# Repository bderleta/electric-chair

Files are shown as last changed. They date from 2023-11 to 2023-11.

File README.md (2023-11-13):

# Electric Chair

AVR Parallel Programmer

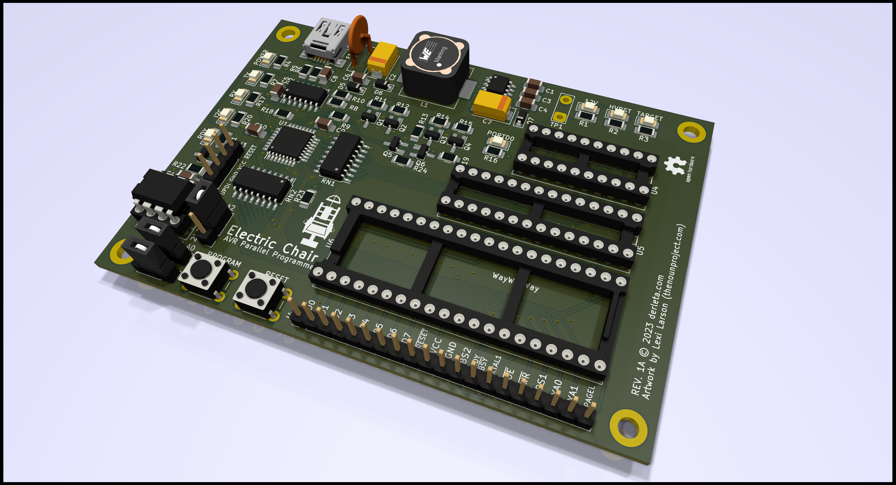
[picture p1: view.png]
Board View REV. 1


## Overview

This is an application of AVRxDB32 MCU with MCP2221A USB-UART/USB-I2C interface chip, implementing parallel programming protocol for ATmega32 and 
other MCUs with similar programming interface. 12V programming voltage is generated onboard by MAX632-based converter.

Firmware stub for AVR128DB32 is available at https://github.com/bderleta/electric-chair-firmware, probably it can be built for other chips from
AVRxDB32 family. The MCP2221A is running at its stock settings and no reconfiguration is necessary, though adjustment of power requirement limit is 
recommended.

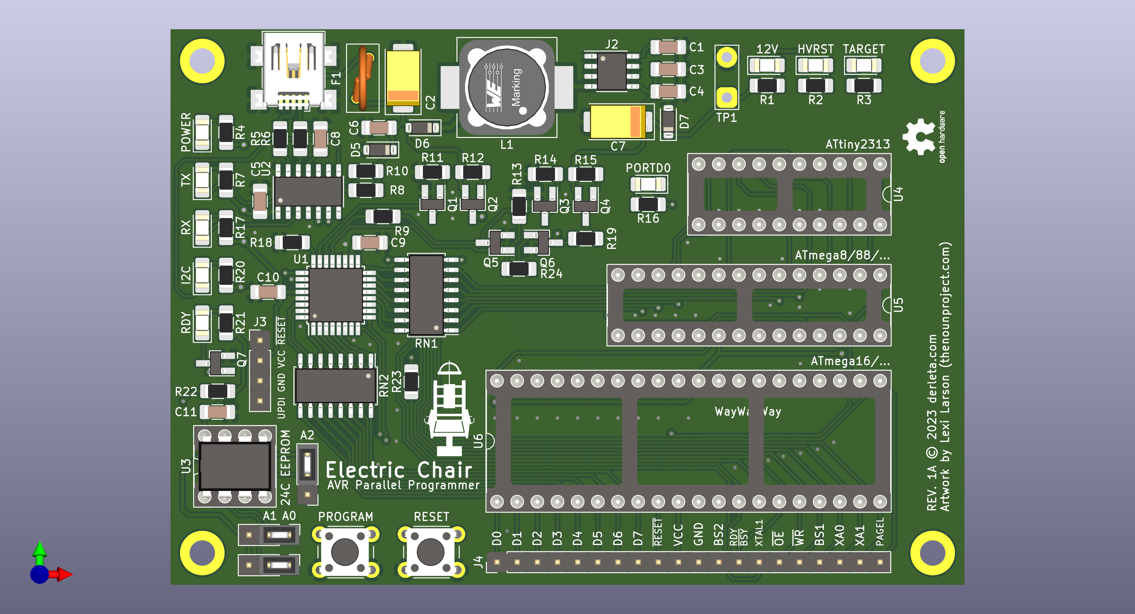
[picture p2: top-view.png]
Board View REV. 1


## Known flaws of first revision
- Significant USB inrush current (can be adjusted by lowering C2 value, but...)
- Converter input ripple of about 100mV (still testing)
- "12V" and "HVRST" leds are consuming majority of converter's output :)

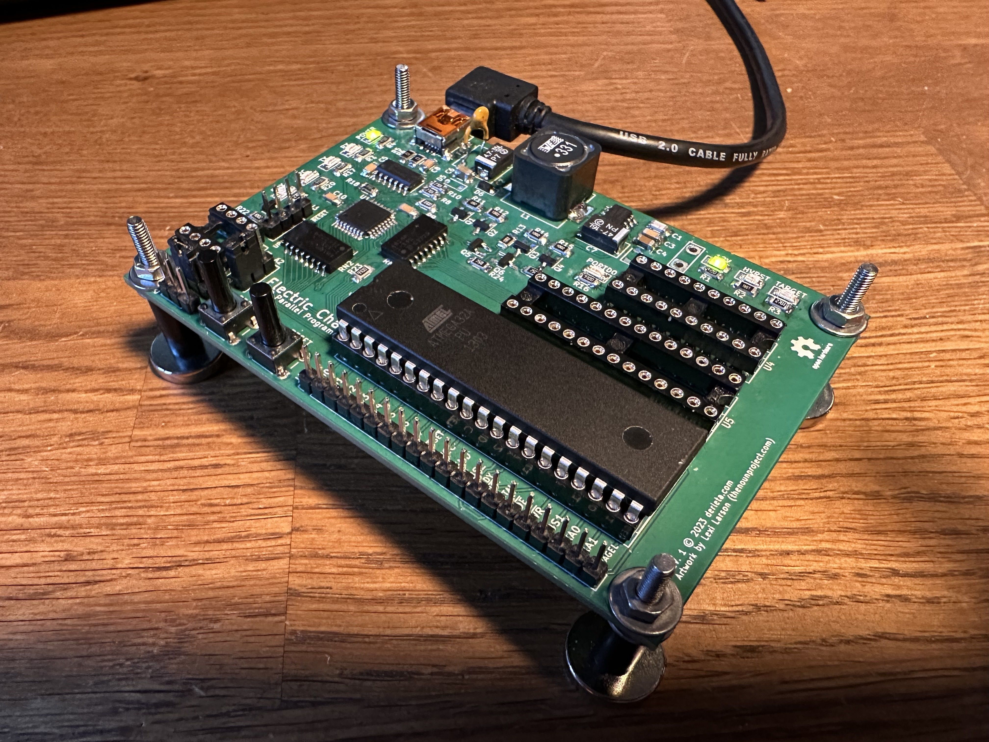
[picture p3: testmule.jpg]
Board View REV. 1 test mule


## Changes coming in second revision

- MAX662-based converter
- XTAL1 line connected to dedicated waveform output of AVR
- PROGRAM button connected to the CCL input in order to enable debouncing using CCL filters
- Elimination of 20-pin socket, instead DIP-40 and DIP-28 ZIF sockets will be placed

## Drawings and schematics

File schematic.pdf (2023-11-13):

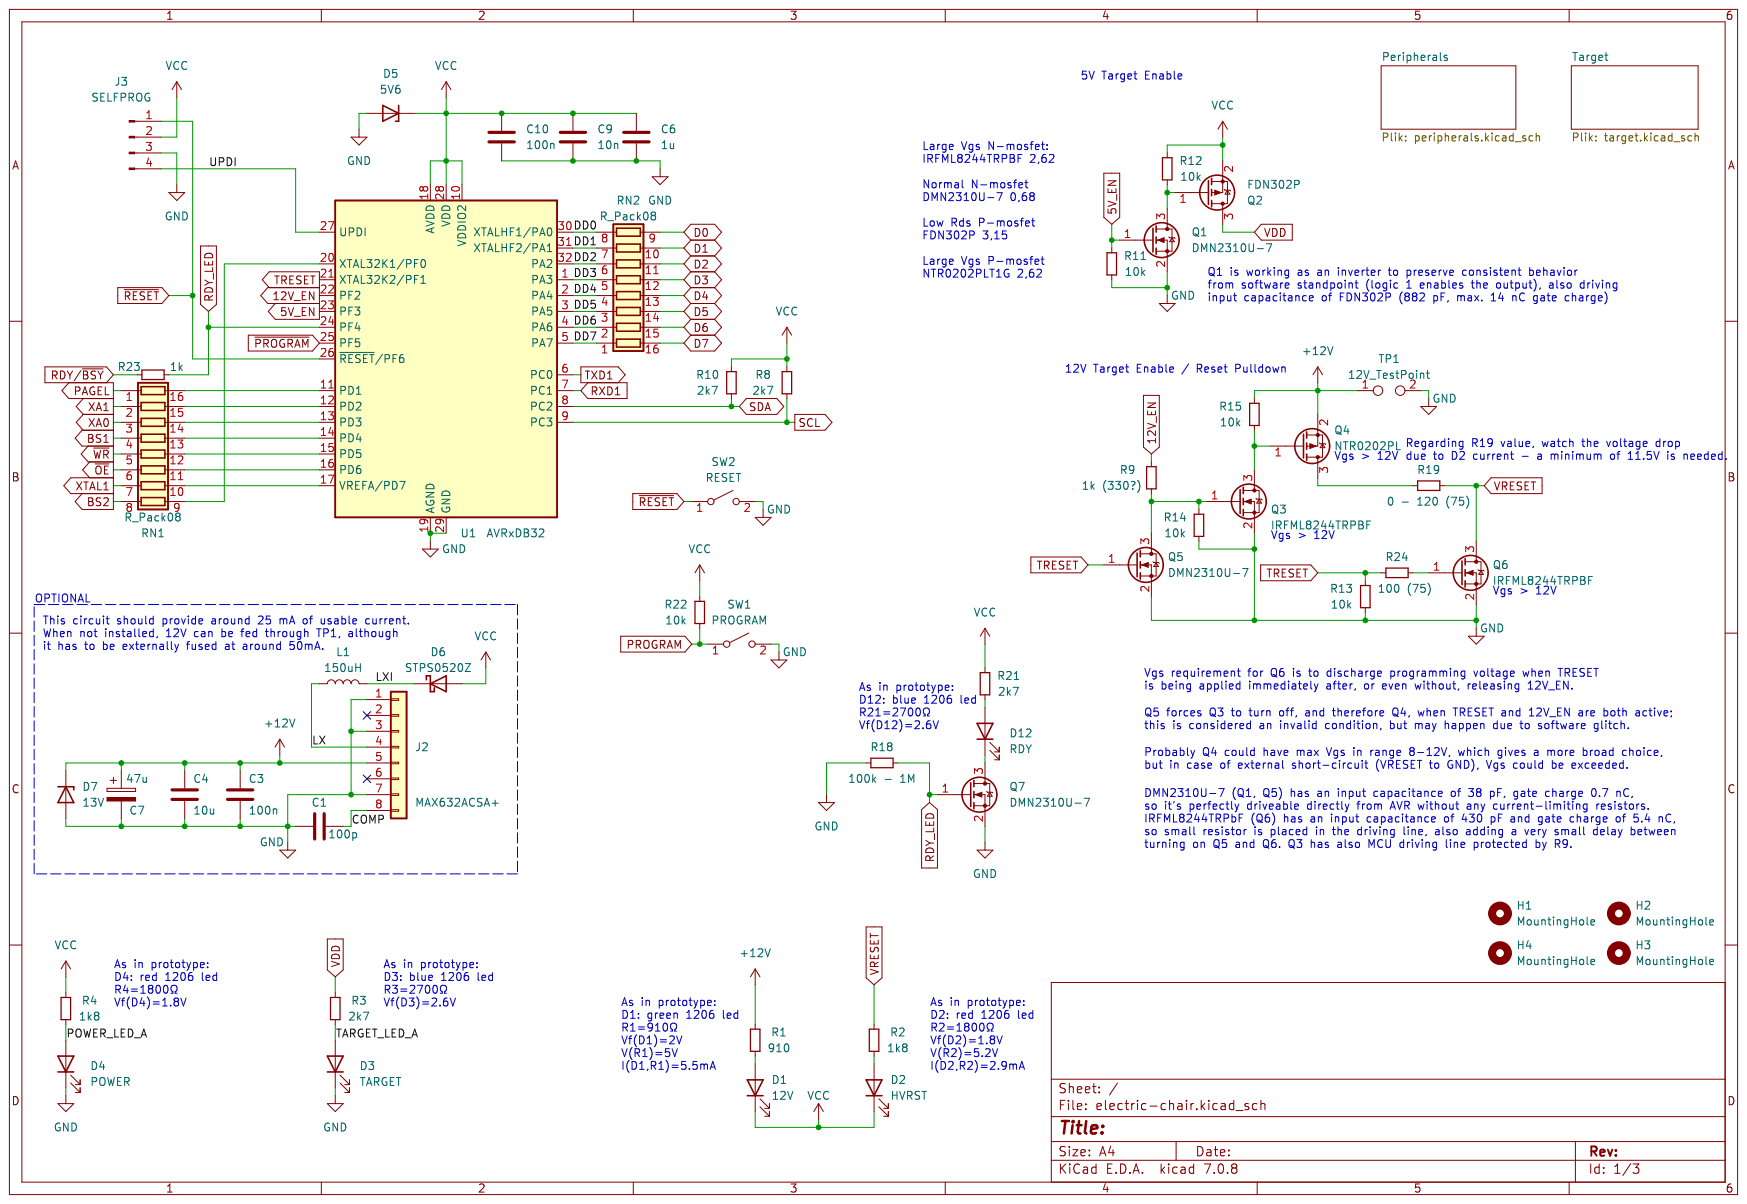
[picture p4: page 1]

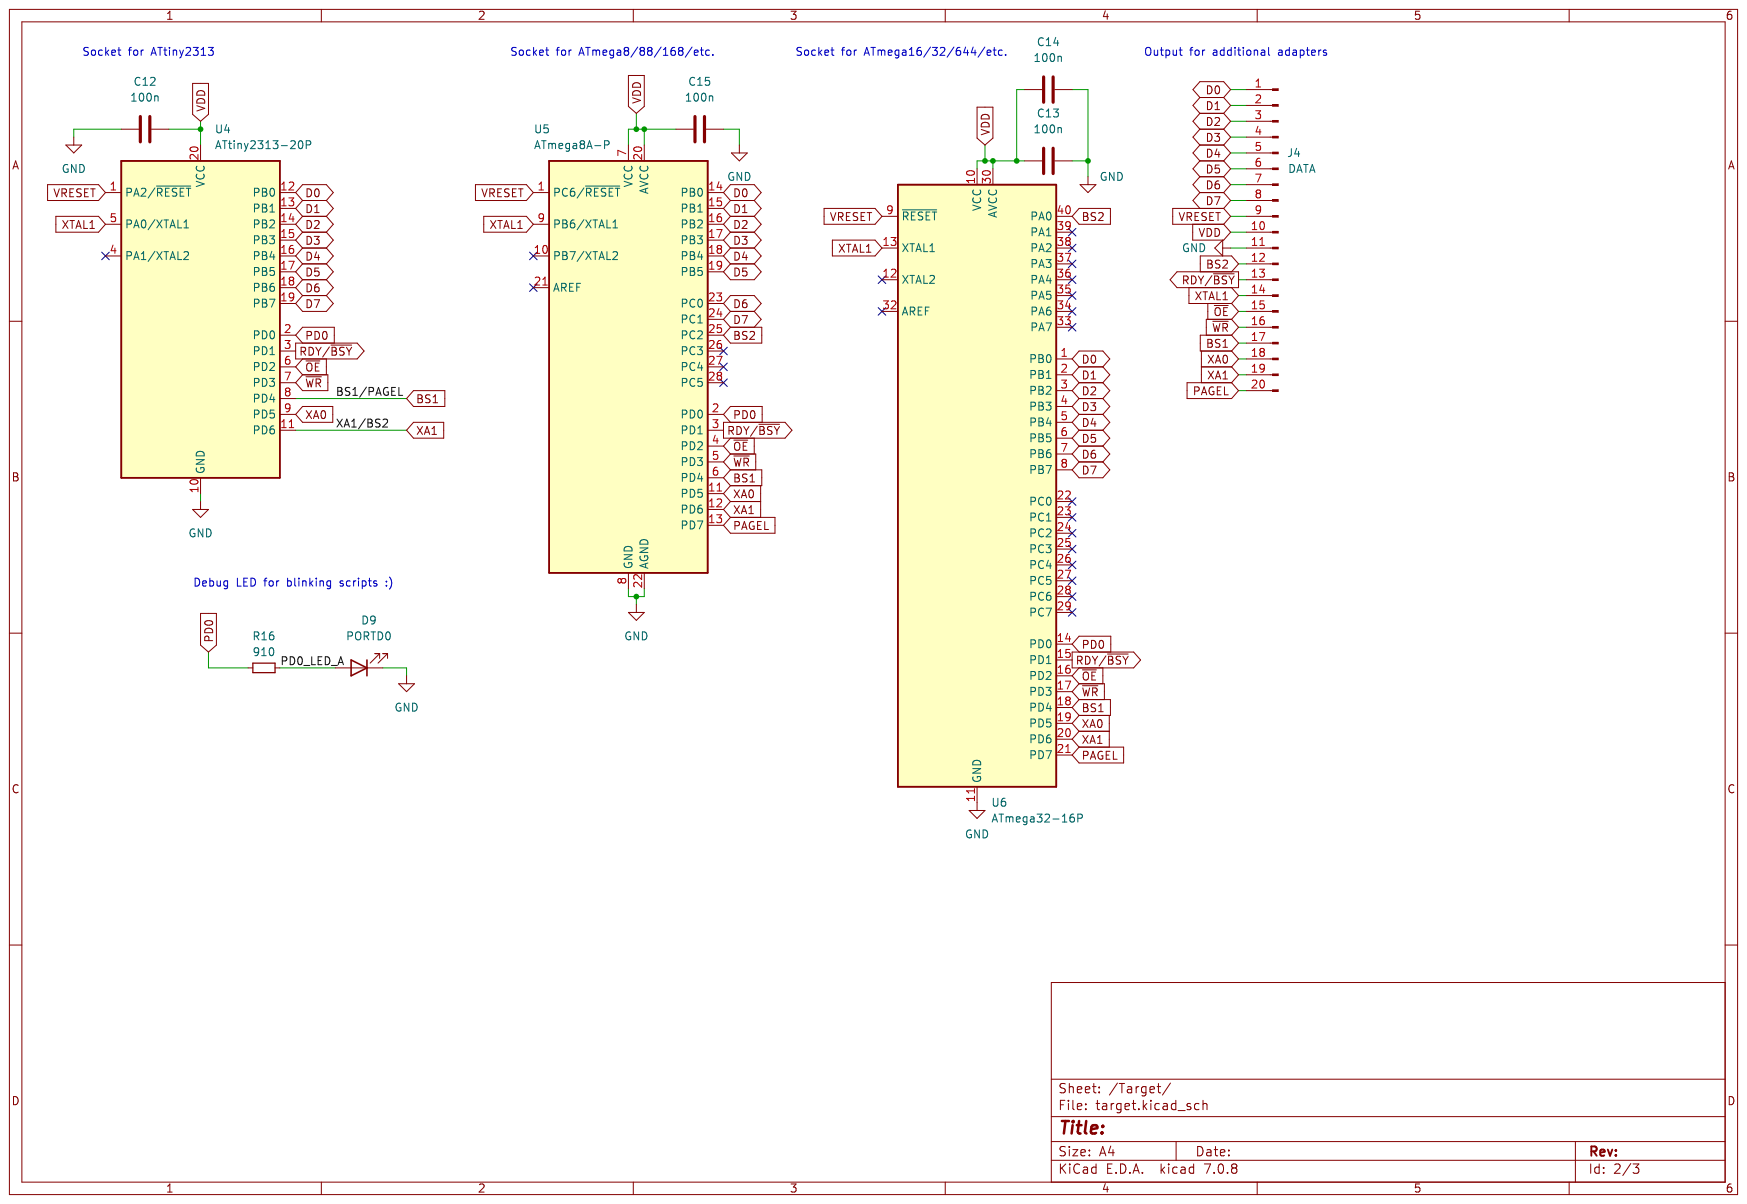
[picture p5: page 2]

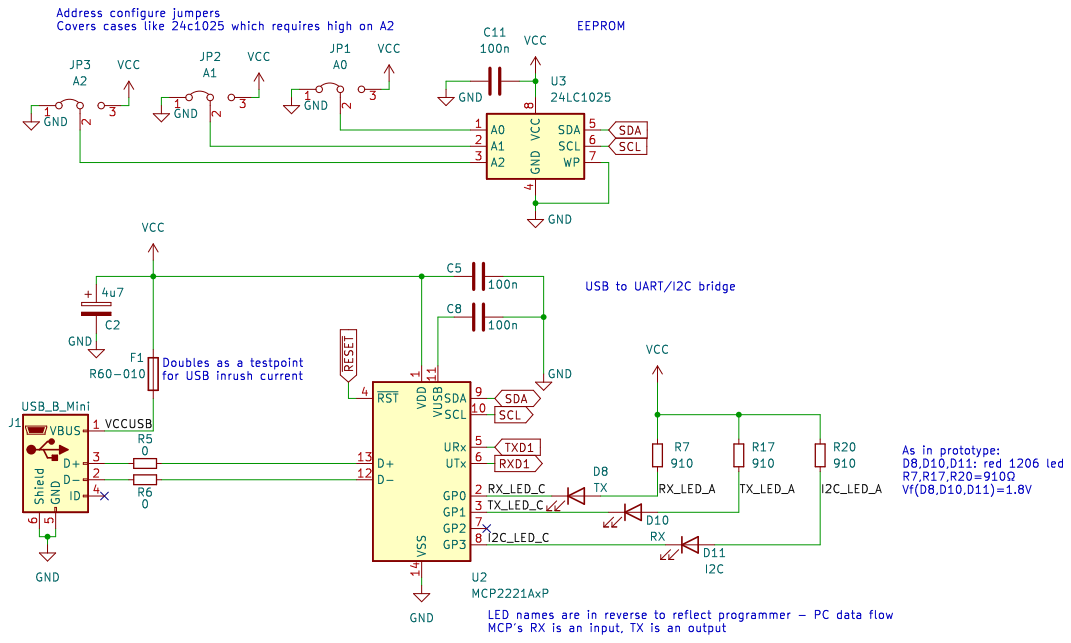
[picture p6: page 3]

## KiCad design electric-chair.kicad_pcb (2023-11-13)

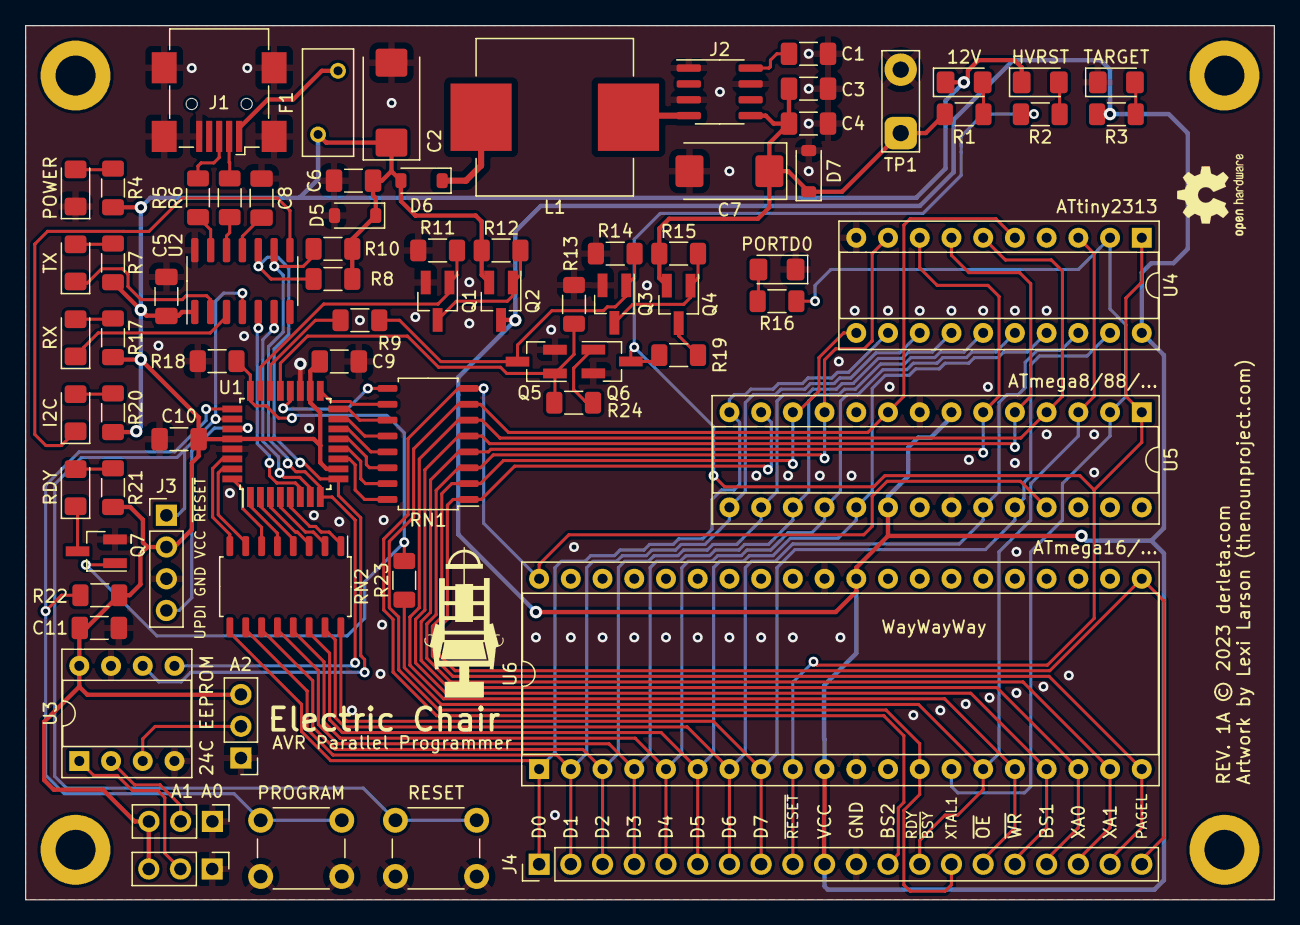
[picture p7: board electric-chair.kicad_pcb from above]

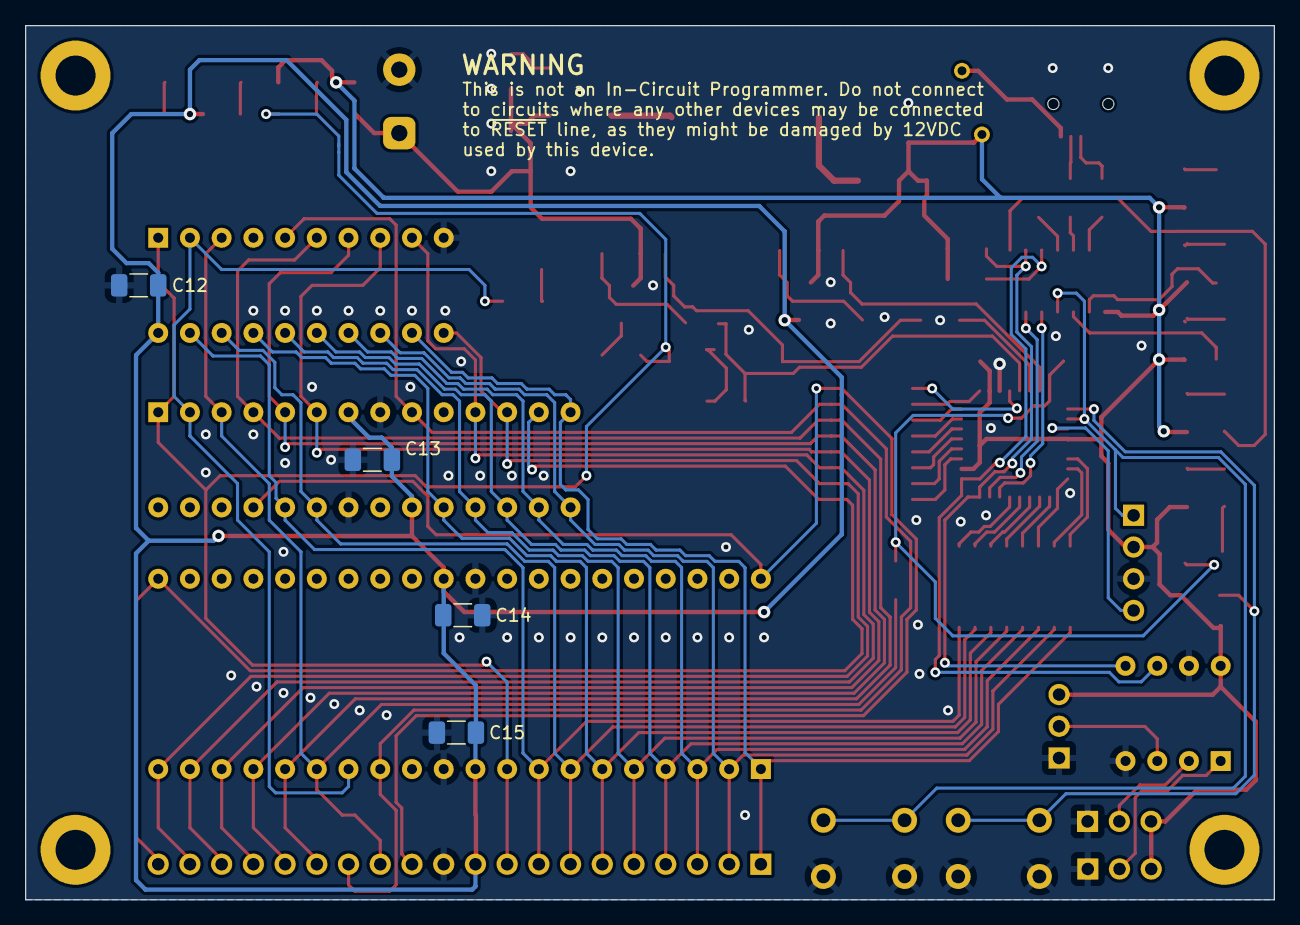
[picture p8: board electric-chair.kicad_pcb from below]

Board: 2 copper layers, 100.0 x 70.0 mm, 82 parts (4 on the bottom side), 80 nets.

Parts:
C1: 100p; C_1206_3216Metric_Pad1.33x1.80mm_HandSolder
C2: 4u7; CP_EIA-7343-31_Kemet-D_Pad2.25x2.55mm_HandSolder
C3, C5, C8, C10, C11, C12, C13, C14, C15: 100n; C_1206_3216Metric_Pad1.33x1.80mm_HandSolder
C4: 10u; C_1206_3216Metric_Pad1.33x1.80mm_HandSolder
C6: 1u; C_1206_3216Metric_Pad1.33x1.80mm_HandSolder
C7: 47u; CP_EIA-7343-31_Kemet-D_Pad2.25x2.55mm_HandSolder
C9: 10n; C_1206_3216Metric_Pad1.33x1.80mm_HandSolder
D1: 12V; LED_1206_3216Metric_Pad1.42x1.75mm_HandSolder
D2: HVRST; LED_1206_3216Metric_Pad1.42x1.75mm_HandSolder
D3: TARGET; LED_1206_3216Metric_Pad1.42x1.75mm_HandSolder
D4: POWER; LED_1206_3216Metric_Pad1.42x1.75mm_HandSolder
D5: 5V6; D_SOD-123
D6: STPS0520Z; D_SOD-123
D7: 13V; D_SOD-123
D8: TX; LED_1206_3216Metric_Pad1.42x1.75mm_HandSolder
D9: PORTD0; LED_1206_3216Metric_Pad1.42x1.75mm_HandSolder
D10: RX; LED_1206_3216Metric_Pad1.42x1.75mm_HandSolder
D11: I2C; LED_1206_3216Metric_Pad1.42x1.75mm_HandSolder
D12: RDY; LED_1206_3216Metric_Pad1.42x1.75mm_HandSolder
F1: R60-010; Fuse_BelFuse_0ZRE0005FF_L8.3mm_W3.8mm
H1, H2, H3, H4: MountingHole; MountingHole_3.2mm_M3_DIN965_Pad
J1: USB_B_Mini; USB_Mini-B_Wuerth_65100516121_Horizontal
J2: MAX632ACSA+; SOIC-8_3.9x4.9mm_P1.27mm
J3: SELFPROG; PinHeader_1x04_P2.54mm_Vertical
J4: DATA; PinHeader_1x20_P2.54mm_Vertical
JP1: A0; PinHeader_1x03_P2.54mm_Vertical
JP2: A1; PinHeader_1x03_P2.54mm_Vertical
JP3: A2; PinHeader_1x03_P2.54mm_Vertical
L1: 150uH; L_Wuerth_WE-PD-Typ-LS_Handsoldering
Q1, Q5, Q7: DMN2310U-7; SOT-23_Handsoldering
Q2: FDN302P; SOT-23_Handsoldering
Q3, Q6: IRFML8244TRPBF; SOT-23_Handsoldering
Q4: NTR0202PL; SOT-23_Handsoldering
R1, R2, R3, R4, R7, R17, R20, R21: 1-2k; R_1206_3216Metric_Pad1.30x1.75mm_HandSolder
R5, R6: 0; R_1206_3216Metric_Pad1.30x1.75mm_HandSolder
R8, R10: 2k7; R_1206_3216Metric_Pad1.30x1.75mm_HandSolder
R9: 1k (330?); R_1206_3216Metric_Pad1.30x1.75mm_HandSolder
R11, R12, R13, R14, R15, R22: 10k; R_1206_3216Metric_Pad1.30x1.75mm_HandSolder
R16: 330; R_1206_3216Metric_Pad1.30x1.75mm_HandSolder
R18: 100k - 1M; R_1206_3216Metric_Pad1.30x1.75mm_HandSolder
R19: 0 - 120 (75); R_1206_3216Metric_Pad1.30x1.75mm_HandSolder
R23: 1k; R_1206_3216Metric_Pad1.30x1.75mm_HandSolder
R24: 100 (75); R_1206_3216Metric_Pad1.30x1.75mm_HandSolder
RN1, RN2: R_Pack08; SOIC-16_4.55x10.3mm_P1.27mm
SW1: PROGRAM; SW_PUSH_6mm
SW2: RESET; SW_PUSH_6mm
TP1: 12V_TestPoint; TestPoint_2Pads_Pitch5.08mm_Drill1.3mm
U1: AVR32DB28x-xSO; TQFP-32_7x7mm_P0.8mm
U2: MCP2221AxP; SOIC-14_3.9x8.7mm_P1.27mm
U3: 24LC1025; DIP-8_W7.62mm_Socket
U4: ATtiny2313-20P; DIP-20_W7.62mm_Socket
U5: ATmega8A-P; DIP-28_W7.62mm_Socket
U6: ATmega32-16P; DIP-40_W15.24mm_Socket

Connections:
5V_EN: Q1.1 (G), R11.2, U1.23 (PF3)
12V_EN: R9.2, U1.22 (PF2)
+12V: C3.1, C4.1, C7.1, D7.1 (K), J2.5, Q4.2 (S), R1.2, R15.2, TP1.1
/COMP: C1.1, J2.8
/DD0: RN2.8 (R8.1), U1.30 (XTALHF1/PA0)
/DD1: RN2.7 (R7.1), U1.31 (XTALHF2/PA1)
/DD2: RN2.6 (R6.1), U1.32 (PA2)
/DD3: RN2.5 (R5.1), U1.1 (PA3)
/DD4: RN2.4 (R4.1), U1.2 (PA4)
/DD5: RN2.3 (R3.1), U1.3 (PA5)
/DD6: RN2.2 (R2.1), U1.4 (PA6)
/DD7: RN2.1 (R1.1), U1.5 (PA7)
/LX: J2.4, L1.1
/LXI: D6.1 (K), L1.2
/POWER_LED_A: D4.2 (A), R4.1
/Peripherals/I2C_LED_A: D11.2 (A), R20.1
/Peripherals/I2C_LED_C: D11.1 (K), U2.8 (GP3)
/Peripherals/RX_LED_A: D8.2 (A), R7.1
/Peripherals/RX_LED_C: D8.1 (K), U2.2 (GP0)
/Peripherals/TX_LED_A: D10.2 (A), R17.1
/Peripherals/TX_LED_C: D10.1 (K), U2.3 (GP1)
/Peripherals/VCCUSB: F1.2, J1.1 (VBUS)
/TARGET_LED_A: D3.2 (A), R3.1
/Target/PD0_LED_A: D9.2 (A), R16.1
/UPDI: J3.4, U1.27 (UPDI)
BS1: J4.17, RN1.4 (R4.1), U4.8 (PD4), U5.6 (PD4), U6.18 (PD4)
BS2: J4.12, RN1.8 (R8.1), U5.25 (PC2), U6.40 (PA0)
D0: J4.1, RN2.9 (R8.2), U4.12 (PB0), U5.14 (PB0), U6.1 (PB0)
D1: J4.2, RN2.10 (R7.2), U4.13 (PB1), U5.15 (PB1), U6.2 (PB1)
D2: J4.3, RN2.11 (R6.2), U4.14 (PB2), U5.16 (PB2), U6.3 (PB2)
D3: J4.4, RN2.12 (R5.2), U4.15 (PB3), U5.17 (PB3), U6.4 (PB3)
D4: J4.5, RN2.13 (R4.2), U4.16 (PB4), U5.18 (PB4), U6.5 (PB4)
D5: J4.6, RN2.14 (R3.2), U4.17 (PB5), U5.19 (PB5), U6.6 (PB5)
D6: J4.7, RN2.15 (R2.2), U4.18 (PB6), U5.23 (PC0), U6.7 (PB6)
D7: J4.8, RN2.16 (R1.2), U4.19 (PB7), U5.24 (PC1), U6.8 (PB7)
GND: C1.2, C2.2, C3.2, C4.2, C5.1, C6.1, C7.2, C8.1, C9.1, C10.1, C11.2, C12.2, C13.1, C14.1, C15.1, D3.1 (K), D4.1 (K), D5.2 (A), D7.2 (A), D9.1 (K), J1.5 (GND), J1.6 (Shield), J2.1, J2.3, J2.7, J3.3, J4.11, JP1.1 (A), JP2.1 (A), JP3.1 (A), Q1.2 (S), Q3.2 (S), Q5.2 (S), Q6.2 (S), Q7.2 (S), R11.1, R13.1, R14.1, R18.2, SW1.2 (B), SW2.2 (B), TP1.2, U1.19 (AGND), U1.29 (GND), U2.14 (VSS), U3.4 (GND), U3.7 (WP), U4.10 (GND), U5.8 (GND), U5.22 (AGND), U6.11 (GND), U6.31 (GND)
unnamed: D1.2 (A), R1.1
unnamed: D2.2 (A), R2.1
unnamed: D12.2 (A), R21.1
unnamed: D12.1 (K), Q7.3 (D)
unnamed: J1.3 (D+), R5.1
unnamed: J1.2 (D-), R6.2
unnamed: JP1.2 (C), U3.1 (A0)
unnamed: JP2.2 (C), U3.2 (A1)
unnamed: JP3.2 (C), U3.3 (A2)
unnamed: Q1.3 (D), Q2.1 (G), R12.1
unnamed: Q3.3 (D), Q4.1 (G), R15.1
unnamed: Q3.1 (G), Q5.3 (D), R9.1, R14.2
unnamed: Q4.3 (D), R19.2
unnamed: Q6.1 (G), R24.2
unnamed: RN1.16 (R1.2), U1.11 (PD1)
unnamed: RN1.15 (R2.2), U1.12 (PD2)
unnamed: RN1.14 (R3.2), U1.13 (PD3)
unnamed: RN1.13 (R4.2), U1.14 (PD4)
unnamed: RN1.12 (R5.2), U1.15 (PD5)
unnamed: RN1.11 (R6.2), U1.16 (PD6)
unnamed: RN1.10 (R7.2), U1.17 (VREFA/PD7)
unnamed: RN1.9 (R8.2), U1.20 (XTAL32K1/PF0)
unnamed: R5.2, U2.13 (D+)
unnamed: R6.1, U2.12 (D-)
unnamed: C8.2, U2.11 (VUSB)
PAGEL: J4.20, RN1.1 (R1.1), U5.13 (PD7), U6.21 (PD7)
PD0: R16.2, U4.2 (PD0), U5.2 (PD0), U6.14 (PD0)
PROGRAM: R22.1, SW1.1 (A)
RDY_LED: Q7.1 (G), R18.1, R23.2, U1.24 (PF4)
RDY/~BSY: J4.13, R23.1, U4.3 (PD1), U5.3 (PD1), U6.15 (PD1)
RXD1: U1.7 (PC1), U2.6 (UTx)
SCL: R8.1, U1.9 (PC3), U2.10 (SCL), U3.6 (SCL)
SDA: R10.1, U1.8 (PC2), U2.9 (SDA), U3.5 (SDA)
TRESET: Q5.1 (G), R13.2, R24.1, U1.21 (XTAL32K2/PF1)
TXD1: U1.6 (PC0), U2.5 (URx)
VCC: C2.1, C5.2, C6.2, C9.2, C10.2, C11.1, D1.1 (K), D2.1 (K), D5.1 (K), D6.2 (A), F1.1, J3.2, JP1.3 (B), JP2.3 (B), JP3.3 (B), Q2.2 (S), R4.2, R7.2, R8.2, R10.2, R12.2, R17.2, R20.2, R21.2, R22.2, U1.10 (VDDIO2), U1.18 (AVDD), U1.28 (VDD), U2.1 (VDD), U3.8 (VCC)
VDD: C12.1, C13.2, C14.2, C15.2, J4.10, Q2.3 (D), R3.2, U4.20 (VCC), U5.7 (VCC), U5.20 (AVCC), U6.10 (VCC), U6.30 (AVCC)
VRESET: J4.9, Q6.3 (D), R2.2, R19.1, U4.1 (PA2/~RESET), U5.1 (PC6/~RESET), U6.9 (~RESET)
XA0: J4.18, RN1.3 (R3.1), U4.9 (PD5), U5.11 (PD5), U6.19 (PD5)
XA1: J4.19, RN1.2 (R2.1), U4.11 (PD6), U5.12 (PD6), U6.20 (PD6)
XTAL1: J4.14, RN1.7 (R7.1), U4.5 (PA0/XTAL1), U5.9 (PB6/XTAL1), U6.13 (XTAL1)
~OE: J4.15, RN1.6 (R6.1), U4.6 (PD2), U5.4 (PD2), U6.16 (PD2)
~RESET: J3.1, SW2.1 (A), U1.26 (~RESET/PF6), U2.4 (~RST)
~WR: J4.16, RN1.5 (R5.1), U4.7 (PD3), U5.5 (PD3), U6.17 (PD3)

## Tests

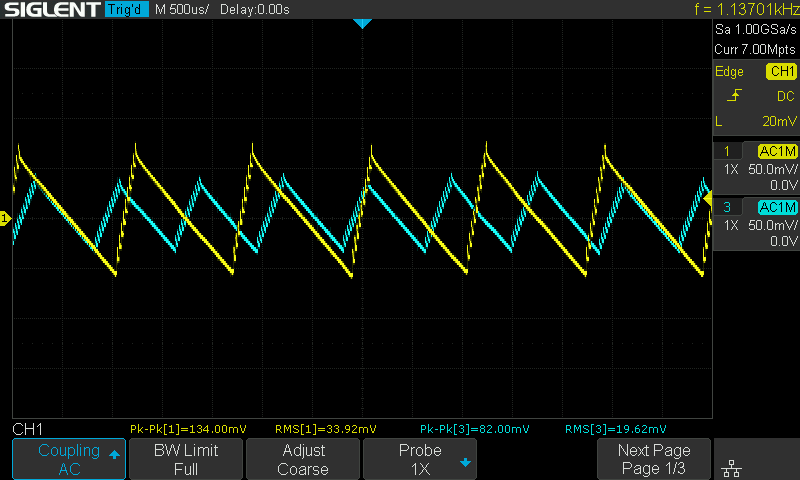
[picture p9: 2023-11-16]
measurements/12v_ripple_yellow-150uh_aqua-330uh.png

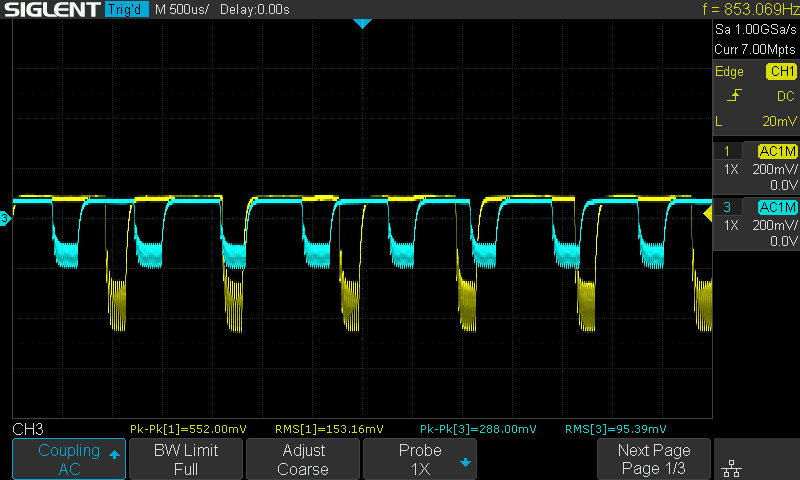
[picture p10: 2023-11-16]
measurements/5v_ripple_12v_ripple_yellow-150uh_aqua-330uh.png

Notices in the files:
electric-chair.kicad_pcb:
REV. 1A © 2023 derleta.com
